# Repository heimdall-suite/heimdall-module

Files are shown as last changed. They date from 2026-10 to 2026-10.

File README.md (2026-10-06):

# heimdall-module

ESP32-C3 based module for the transmitter's JR module bay, part of the Heimdall Suite.

## Status

Hardware rev 2 (KiCad 10, `hardware/kicad/`): schematic reviewed and corrected,
board re-placed and re-routed from the first EasyEDA layout. Not built or tested
yet. The EasyEDA originals are kept in `hardware/easyeda-archive/`. No firmware yet.

KiCad 3D renders of rev 2:

| Top, angled | Bottom, angled |
|---|---|
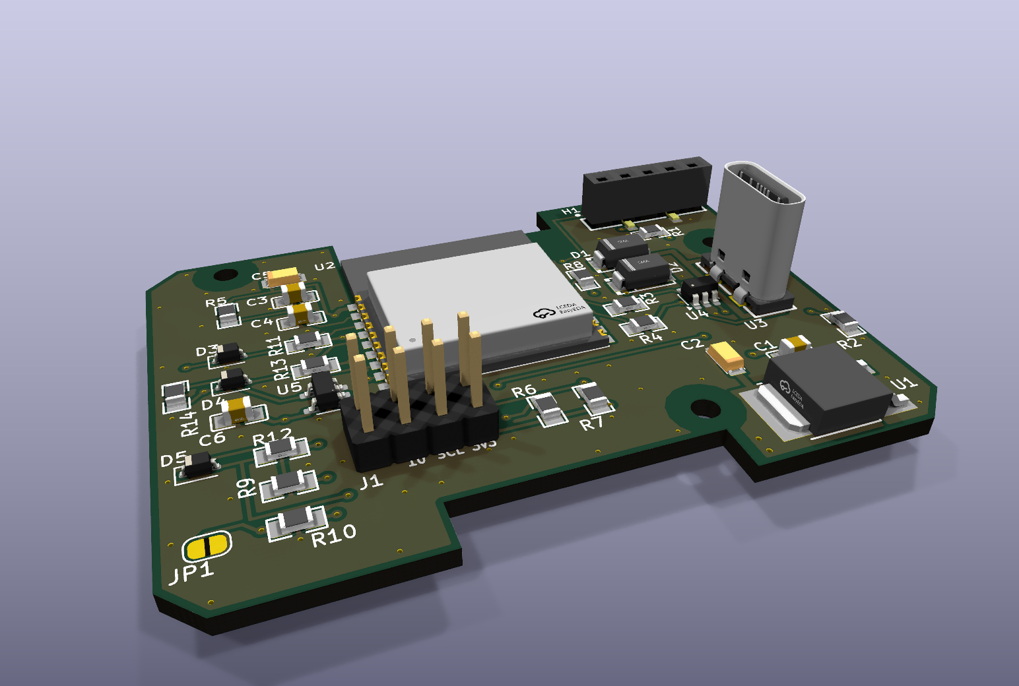
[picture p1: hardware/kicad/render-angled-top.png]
Board, 3D top, angled
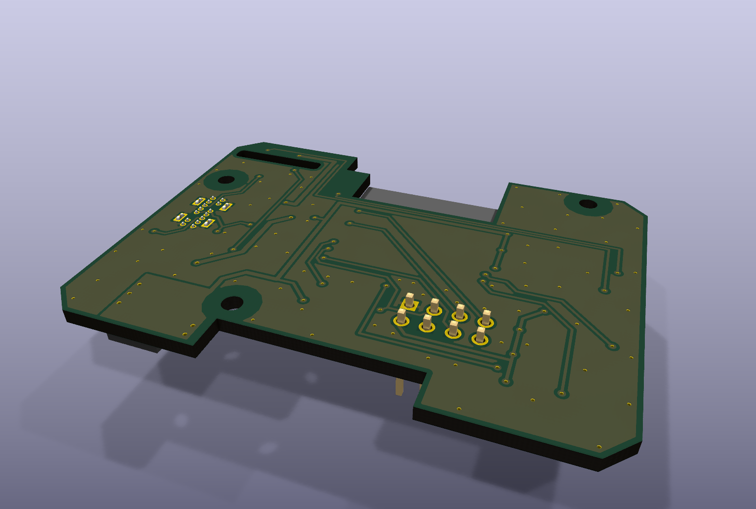
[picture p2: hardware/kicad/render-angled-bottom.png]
Board, 3D bottom, angled
|  |  |

| Top | Bottom (mirrored, as seen from below) |
|---|---|
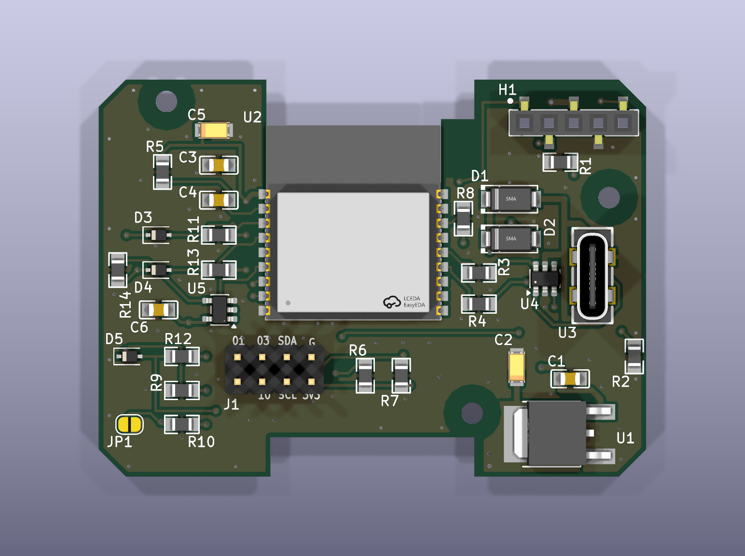
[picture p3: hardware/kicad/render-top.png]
Board, 3D top
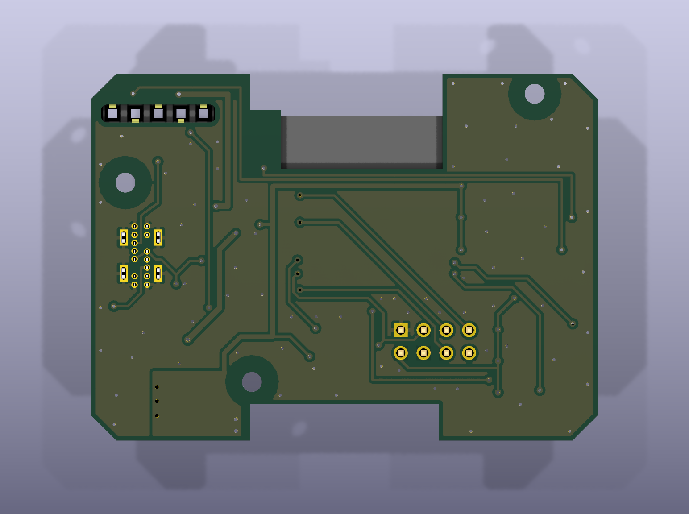
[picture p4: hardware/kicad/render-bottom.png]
Board, 3D bottom
|  |  |

## Case

The board is shaped for the 3D-printed case `MULTI-Module_Bangood_4-in-1_Case.stl`
(the STL is not in this repo). The figures below were measured from that STL:

- The outline is the case cavity (57 x 41.5 mm) minus 0.3 mm all round. It has
  notches for the two latch housings, which reach 4 mm in from the long walls.
  The top notch merges with the cut-out under the ESP32 module's antenna.
- The four corners are chamfered 45° (2.8 mm legs). The lid screw holes
  (1.7 mm) sit in 3.5 mm bosses in the cavity corners, from about 11 mm above
  the floor upwards. The board has to pass them on the way down to the
  standoffs, and the chamfers leave about 0.47 mm to each boss.
- MH1-MH3 are 2.2 mm holes for 2 mm self-tapping screws into the case's three
  standoffs (4.5 mm, 1.8 mm pilot holes, tops 5 mm above the floor).
  The lid uses the same screws. The copper keeps 3 mm clear of each hole.
- The bay pins come up through the floor opening and the H1 slot into the
  female header on top.
- **H1 position:** taken from three existing JR-bay designs. All three put the
  bay pins about 1.25 mm closer to the end wall than the centre of the case's
  floor opening:
  - DIY Multiprotocol STM32 v1.0t (Eagle)
  - Multiprotocol V2 (Gerbers)
  - ExpressLRS TX_SX1280 (Gerbers)

  This is not yet checked against a real radio.
- The case still needs an opening for the USB-C connector.

`case_place.py` moved the rev 2 parts into the case outline. `spread_place.py`
then spread them for hand soldering: at least 1 mm between courtyards left of the
module, and U1 moved down to the bottom edge. A few pairs on the USB side are
still closer. `route_pcb.py prep` draws the hand routes; Freerouting and the
later `route_pcb.py` steps do the rest.

## Pin assignment (rev 2)

| Function | ESP32-C3 GPIO | Via |
|---|---|---|
| Bay SIGNAL / PPM (H1 pin 1), input | IO4 | D3, R11 4.7k pull-up |
| Bay DATA / S.Port (H1 pin 5), receive | IO5 | D4, R13 4.7k pull-up |
| Bay DATA / S.Port (H1 pin 5), transmit | IO7 | U5 74LVC1G34 + R14 1k |
| Bay HB (H1 pin 2), output | IO8 | D5 (pull low only), R9 doubles as its pull-up |
| I2C SDA / SCL (J1, 10k pull-ups) | GPIO20 / GPIO21 (U0RXD / U0TXD) | |
| Breakout (J1) | IO1, IO3, IO10 | |
| USB D- / D+ | IO18 / IO19 | R4 / R3 33R |
| Strapping | IO2, IO8 (HB), IO9 pulled up 10k; JP1 BOOT bridges IO9 to GND | |

IO0 and IO6 are unused. UART0's pins carry I2C, so the console has to run over
USB-Serial/JTAG.

## Bay interface

The bay lines never connect straight to the ESP32.

- SIGNAL (PPM in) and DATA receive go through a BAT54WS Schottky with its
  cathode at the bay, the same scheme as the DIY Multiprotocol module (STM32
  board v1.0t, BAT48 diodes). The radio can only pull the line low; the high
  level comes from our 3V3 pull-ups (R11, R13), so a radio that drives 5 V
  never reaches the ESP32.
- HB (out) goes through a Schottky with its anode at the bay: the ESP32 can
  only pull it low, R12 (4.7k) pulls it high on the bay side.
- DATA transmit goes through U5, a 74LVC1G34 buffer (5.5 V tolerant, always on),
  and R14 (1k). The UART's idle level holds the line, so the same hardware
  works for CRSF (idle high) and inverted S.Port (idle low); which one is a
  firmware setting. When the radio transmits it overrides the 1k (about
  3.3 mA). Against a 10k pull-up on the radio side, an S.Port idle low sits at
  about 0.3 V (calculated, not measured).

DATA is half duplex on one wire, with separate receive and transmit pins
(IO5/IO7). The receive pin also sees the module's own transmitted bytes, so
firmware has to discard that echo. Inversion is done in the ESP32-C3's UART.
Use IO8 (HB) as an output only after boot: it is a strapping pin, which is
safe here because download mode needs USB, and USB and the bay can't be
connected at the same time.

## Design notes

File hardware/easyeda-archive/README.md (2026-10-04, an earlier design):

# EasyEDA Pro archive

The original heimdall-module design was drawn in EasyEDA Pro 3.2 (project
"Atmosphere module") before the move to KiCad. These files are kept
unmodified as a reference:

- `Schematic1.epro`, `PCB1.epro` — per-document exports from EasyEDA Pro
  (2026-10-04). The full project's native `.epro2` format can't be read by
  the KiCad 10 importer, these older-format exports can.
- `merge_epro.py` — joins the two exports into one linked project,
  `heimdall-module.epro`, for KiCad's File → Import → Non-KiCad Project.

Once imported, `hardware/kicad/` is the source of truth; nothing here is
edited further.

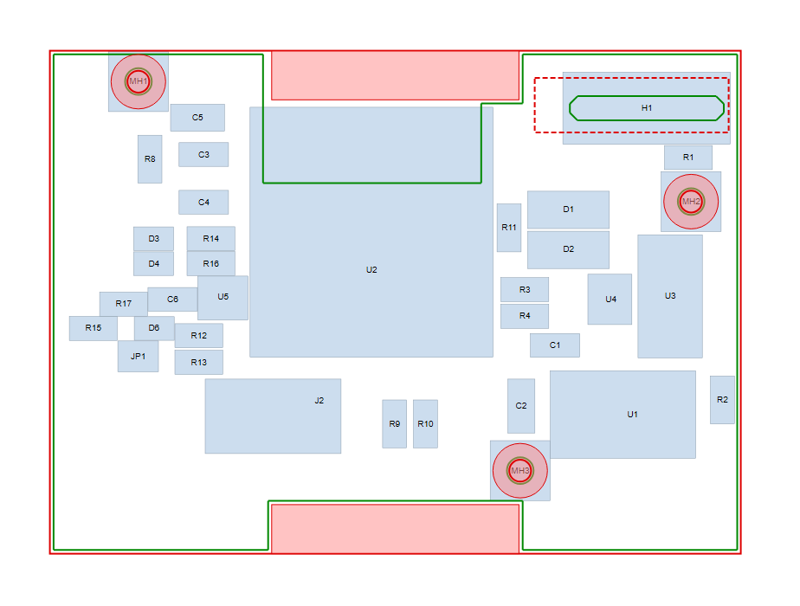
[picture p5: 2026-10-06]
hardware/kicad/placement-overlay.png

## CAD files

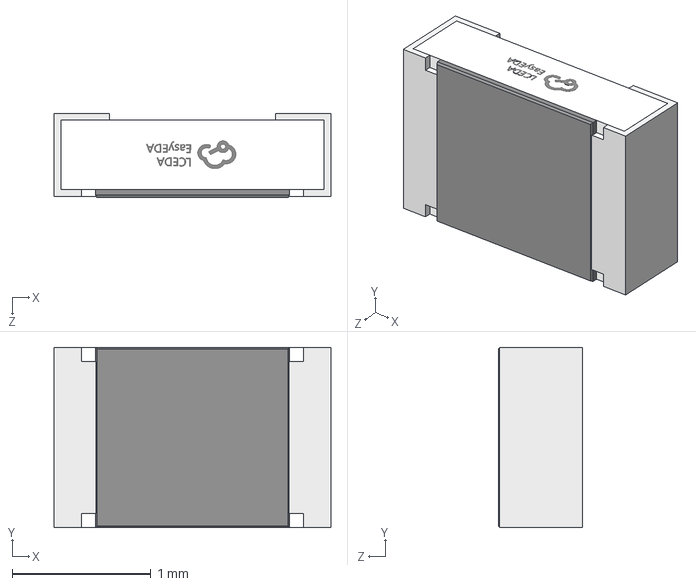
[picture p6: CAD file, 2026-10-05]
hardware/kicad/EASYEDA_MODELS/R0805_L2.0-W1.3-H0.6.step
2.00 x 1.30 x 0.61 mm

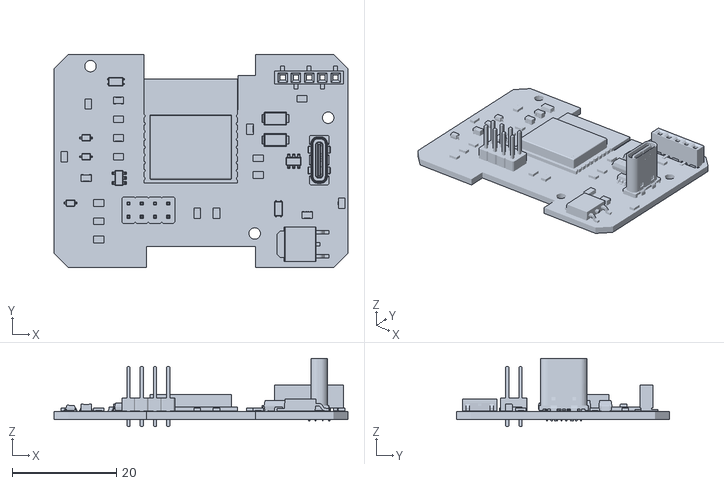
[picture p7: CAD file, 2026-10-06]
hardware/kicad/pcb.stl
56.4 x 40.9 x 13.1

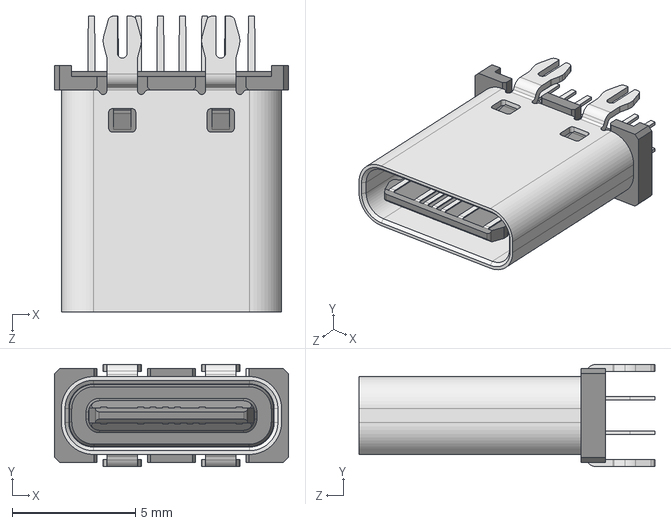
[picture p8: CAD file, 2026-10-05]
hardware/kicad/EASYEDA_MODELS/USB-TYPE-C-TH_TYPEC-214-ARP14H105.step
9.50 x 4.16 x 12.0 mm

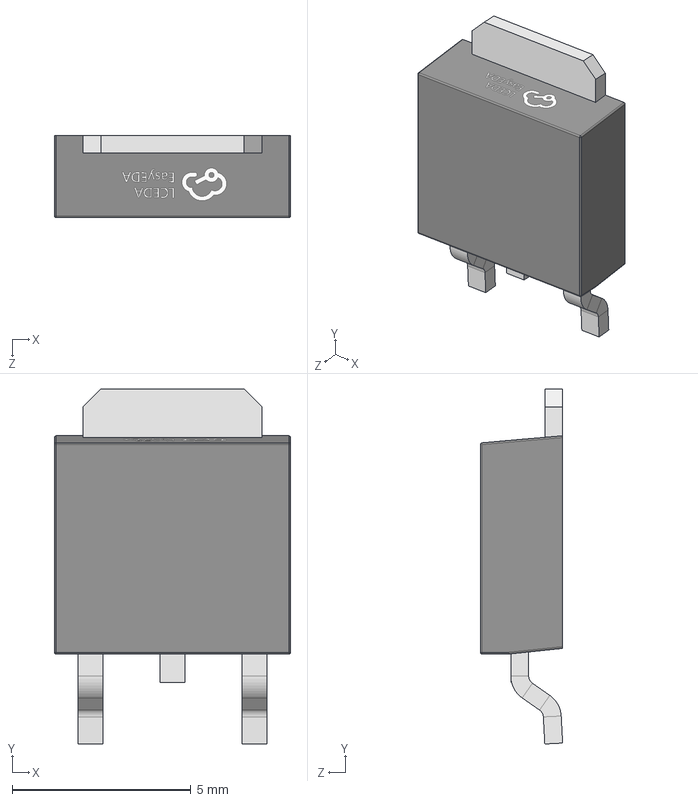
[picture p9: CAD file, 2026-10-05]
hardware/kicad/EASYEDA_MODELS/TO-252-2L-3P_L6.6-W6.1-H2.3-LS10.1-P4.6.step
6.60 x 9.92 x 2.30 mm

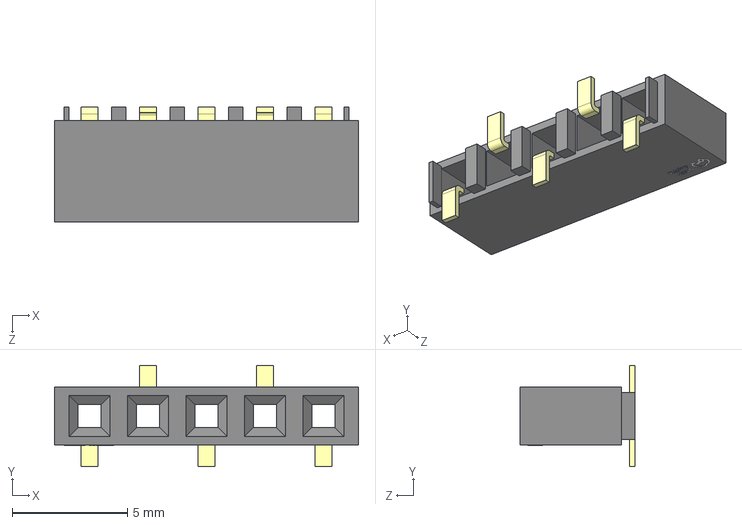
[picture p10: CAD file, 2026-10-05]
hardware/kicad/EASYEDA_MODELS/HDR-SMD_5P-P2.54-V-F-LS4.4.step
13.2 x 4.40 x 5.00 mm

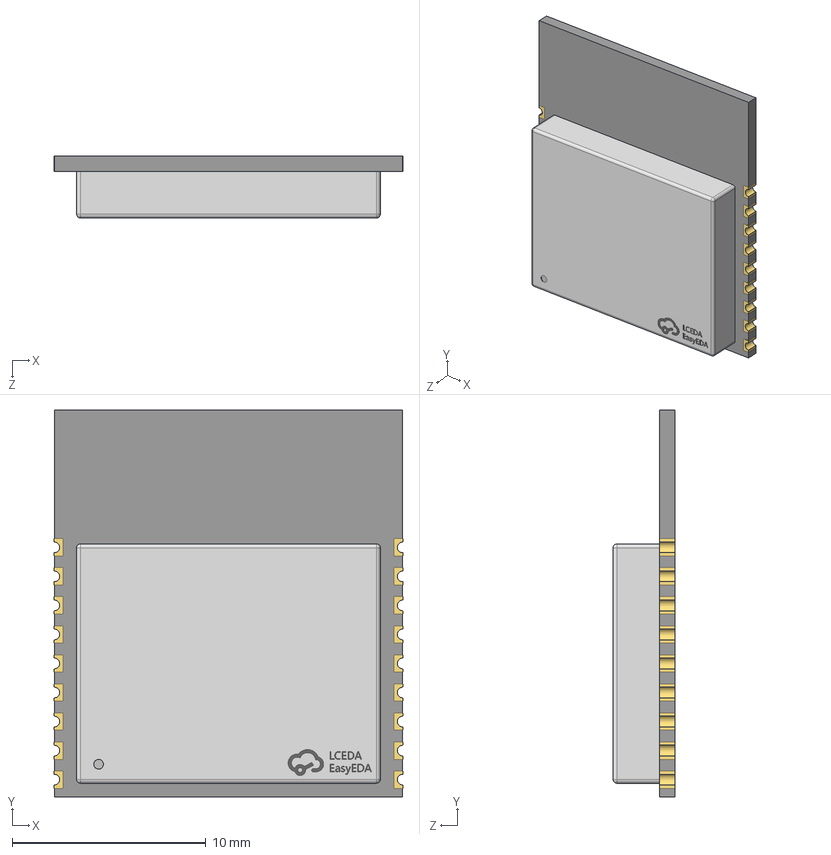
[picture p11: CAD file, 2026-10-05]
hardware/kicad/EASYEDA_MODELS/BULETM-SMD_ESPRESSIF_ESP32-C3-WROOM-02-N4-4MB.step
18.0 x 20.0 x 3.22 mm

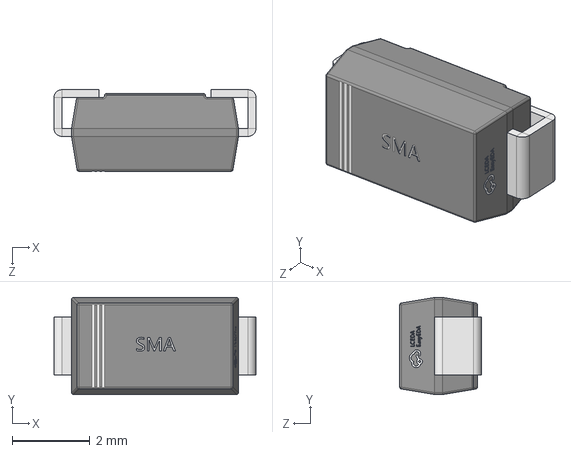
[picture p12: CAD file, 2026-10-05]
hardware/kicad/EASYEDA_MODELS/SMA_L4.4-W2.6-LS5.0-RD.step
5.20 x 2.50 x 2.10 mm

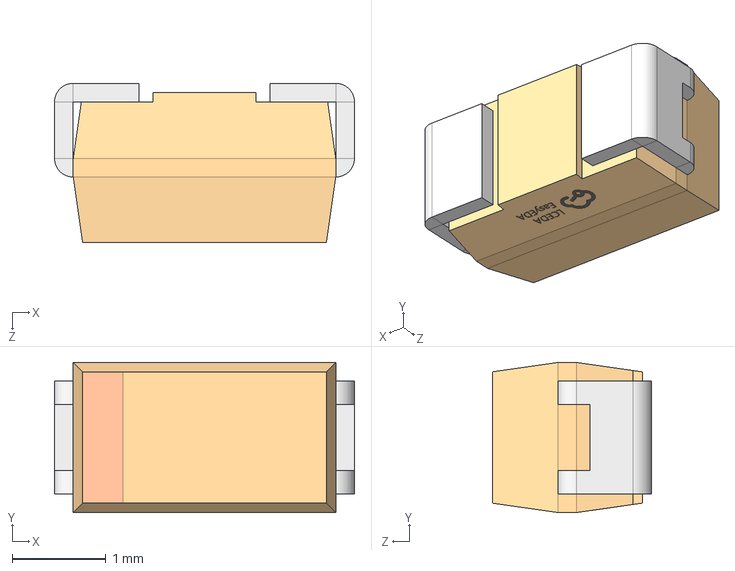
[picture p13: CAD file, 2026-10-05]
hardware/kicad/EASYEDA_MODELS/CASE-A_3216.step
3.20 x 1.60 x 1.70 mm

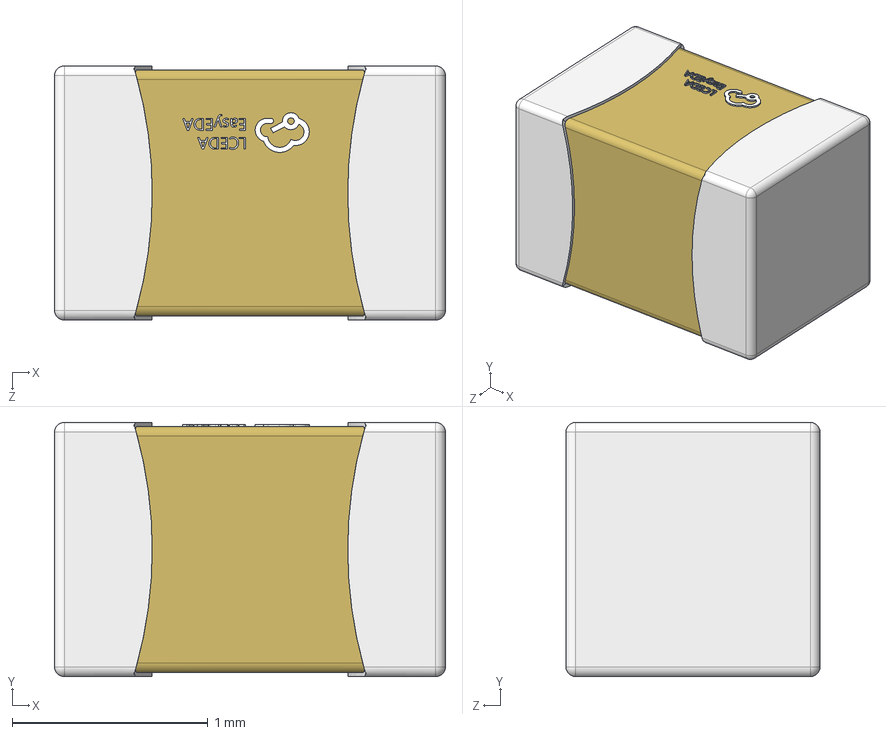
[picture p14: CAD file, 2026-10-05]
hardware/kicad/EASYEDA_MODELS/C0805_L2.0-W1.3-H1.3.step
2.00 x 1.30 x 1.30 mm

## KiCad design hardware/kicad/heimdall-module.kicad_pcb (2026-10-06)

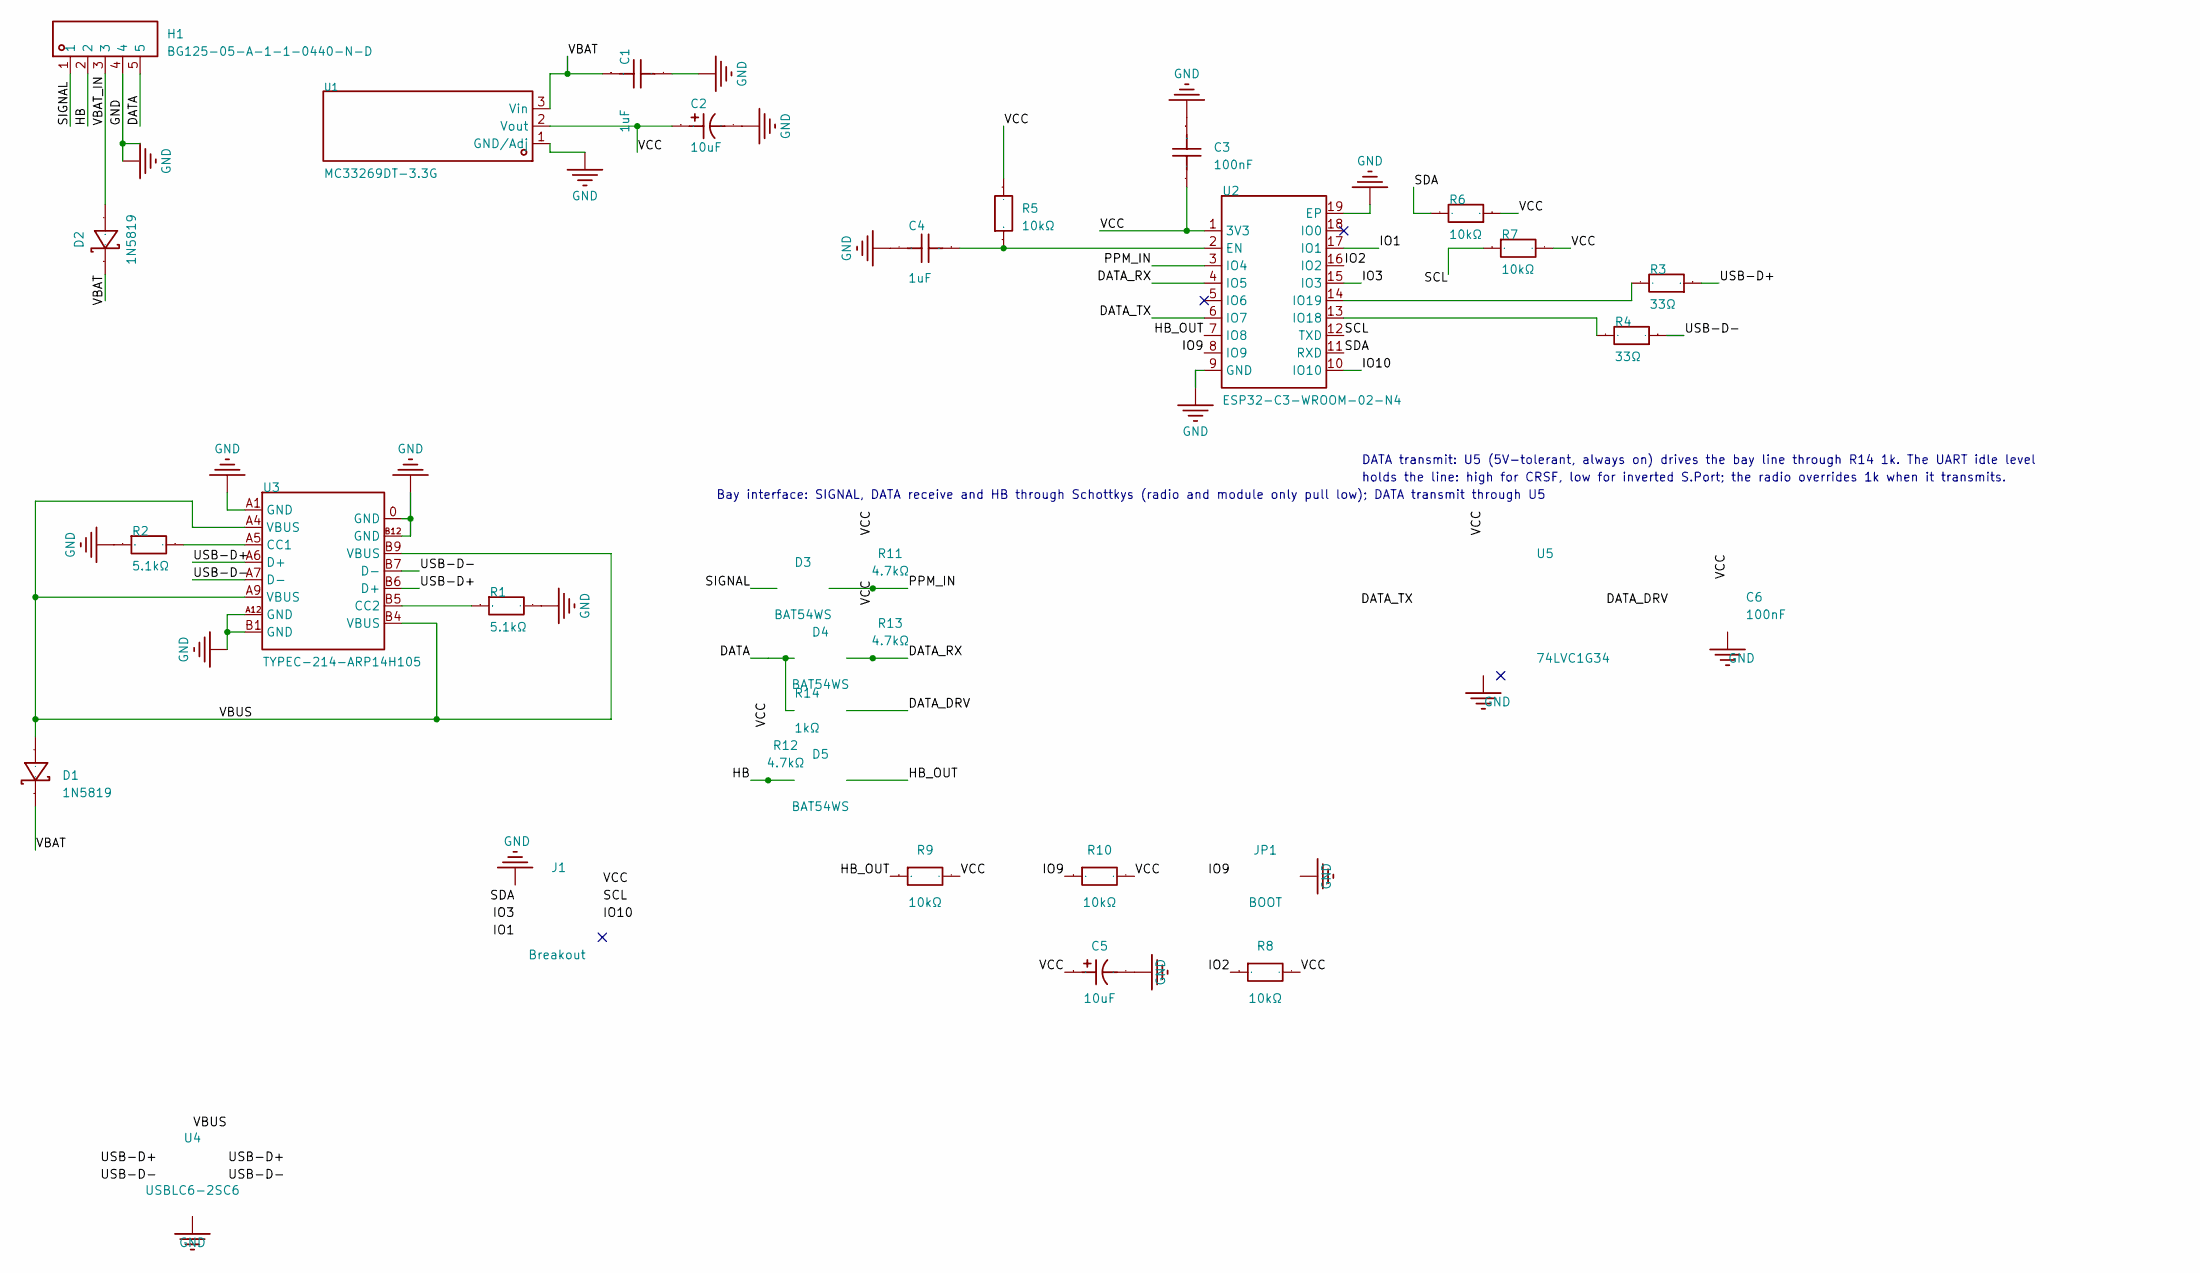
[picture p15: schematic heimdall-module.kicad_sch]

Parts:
C1, C4: 1uF; C0805; Manufacturer Part GCM21BR71H105KA03L
C2: 10uF; CASE-A_3216; Manufacturer Part T491A106K010AT; LCSC Part Name 10uF ±10% 10V
C3: 100nF; C0805; Manufacturer Part GRM21B7U1A104JA01L; LCSC Part Name 100nF ±5% 10V
C5: 10uF; CASE-A_3216; Manufacturer Part T491A106K010AT
C6: 100nF; C0805; Manufacturer Part GRM21B7U1A104JA01L
D1: 1N5819; SMA_L4.4-W2.6-LS5.0-RD; Manufacturer Part 1N5819; LCSC Part Name KEXIN(科信)原型号 SS14,后续变更为 1N5819，丝印不变。 电压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
D2: 1N5819; SMA_L4.4-W2.6-LS5.0-RD; Manufacturer Part 1N5819
D3, D4, D5: BAT54WS; D_SOD-323; Manufacturer Part BAT54WS-7-F
H1: BG125-05-A-1-1-0440-N-D; HDR-SMD_5P-P2.54-V-F-LS4.4; Manufacturer Part BG125-05-A-1-1-0440-N-D; LCSC Part Name 1x5P 间距:2.54mm 立贴
J1: Breakout; PinHeader_2x04_P2.54mm_Vertical
JP1: BOOT; SolderJumper-2_P1.3mm_Open_RoundedPad1.0x1.5mm
R1, R2: 5.1kΩ; R0805; Manufacturer Part ERA6AEB512V; LCSC Part Name 薄膜电阻 5.1kΩ ±0.1% 125mW
R3, R4: 33Ω; R0805; Manufacturer Part ERJ6ENF33R0V; LCSC Part Name 33Ω ±1% 125mW 厚膜电阻
R5, R6, R7: 10kΩ; R0805; Manufacturer Part ERJP06F1002V; LCSC Part Name 10kΩ ±1% 500mW 厚膜电阻
R8, R9, R10: 10kΩ; R0805; Manufacturer Part ERJP06F1002V
R11, R12, R13: 4.7kΩ; R0805; Manufacturer Part ERJ-6ENF4701V
R14: 1kΩ; R0805; Manufacturer Part ERJ-6ENF1001V
U1: MC33269DT-3.3G; TO-252-2_L6.6-W6.1-P4.57-LS9.9-BR-CW; Manufacturer Part MC33269DT-3.3G; LCSC Part Name 3.3V 800mA 20V
U2: ESP32-C3-WROOM-02-N4; BULETM-SMD_ESPRESSIF_ESP32-C3-WROOM-02-N4-4MB; Manufacturer Part ESP32-C3-WROOM-02-N4; LCSC Part Name 不带固件 2.4GHz Wi-Fi（802.11b/g/n）+ 蓝牙5模组
U3: TYPEC-214-ARP14H105; USB-TYPE-C-TH_TYPEC-214-ARP14H105; Manufacturer Part TYPEC-214-ARP14H105; LCSC Part Name Type-C 母 直插
U4: USBLC6-2SC6; SOT-23-6; Manufacturer Part USBLC6-2SC6
U5: 74LVC1G34; SOT-23-5; Manufacturer Part SN74LVC1G34DBVR

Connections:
/DATA: D4.1 (K), H1.5, R14.1
/DATA_DRV: R14.2, U5.4
/DATA_RX: D4.2 (A), R13.2, U2.4 (IO5)
/DATA_TX: U2.6 (IO7), U5.2
/HB: D5.2 (A), H1.2, R12.2
/HB_OUT: D5.1 (K), R9.1, U2.7 (IO8)
/IO1: J1.7, U2.17 (IO1)
/IO2: R8.1, U2.16 (IO2)
/IO3: J1.5, U2.15 (IO3)
/IO9: JP1.1 (A), R10.1, U2.8 (IO9)
/IO10: J1.6, U2.10 (IO10)
/PPM_IN: D3.2 (A), R11.2, U2.3 (IO4)
/SCL: J1.4, R7.1, U2.12 (TXD)
/SDA: J1.3, R6.2, U2.11 (RXD)
/SIGNAL: D3.1 (K), H1.1
/USB-D+: R3.1, U3.A6 (D+), U3.B6 (D+), U4.1 (I/O1), U4.6 (I/O1)
/USB-D-: R4.1, U3.A7 (D-), U3.B7 (D-), U4.3 (I/O2), U4.4 (I/O2)
/VBAT: C1.1, D1.1 (C), D2.1 (C), U1.3 (Vin)
/VBAT_IN: D2.2 (A), H1.3
/VBUS: D1.2 (A), U3.A4 (VBUS), U3.A9 (VBUS), U3.B4 (VBUS), U3.B9 (VBUS), U4.5 (VBUS)
/VCC: C2.1, C3.2, C5.1, C6.1, J1.2, R5.2, R6.1, R7.2, R8.2, R9.2, R10.2, R11.1, R12.1, R13.1, U1.2 (Vout), U2.1 (3V3), U5.5 (VCC)
GND: C1.2, C2.2, C3.1, C4.2, C5.2, C6.2, H1.4, J1.1, JP1.2 (B), R1.2, R2.1, U1.1 (GND/Adj), U2.9 (GND), U2.19 (EP), U3.0 (GND), U3.A1 (GND), U3.A12 (GND), U3.B1 (GND), U3.B12 (GND), U4.2 (GND), U5.3 (GND)
unnamed: C4.1, R5.1, U2.2 (EN)
unnamed: R4.2, U2.13 (IO18)
unnamed: R3.2, U2.14 (IO19)
unnamed: R2.2, U3.A5 (CC1)
unnamed: R1.1, U3.B5 (CC2)

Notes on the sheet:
Bay interface: SIGNAL, DATA receive and HB through Schottkys (radio and module only pull low); DATA transmit through U5
DATA transmit: U5 (5V-tolerant, always on) drives the bay line through R14 1k. The UART idle level
holds the line: high for CRSF, low for inverted S.Port; the radio overrides 1k when it transmits.

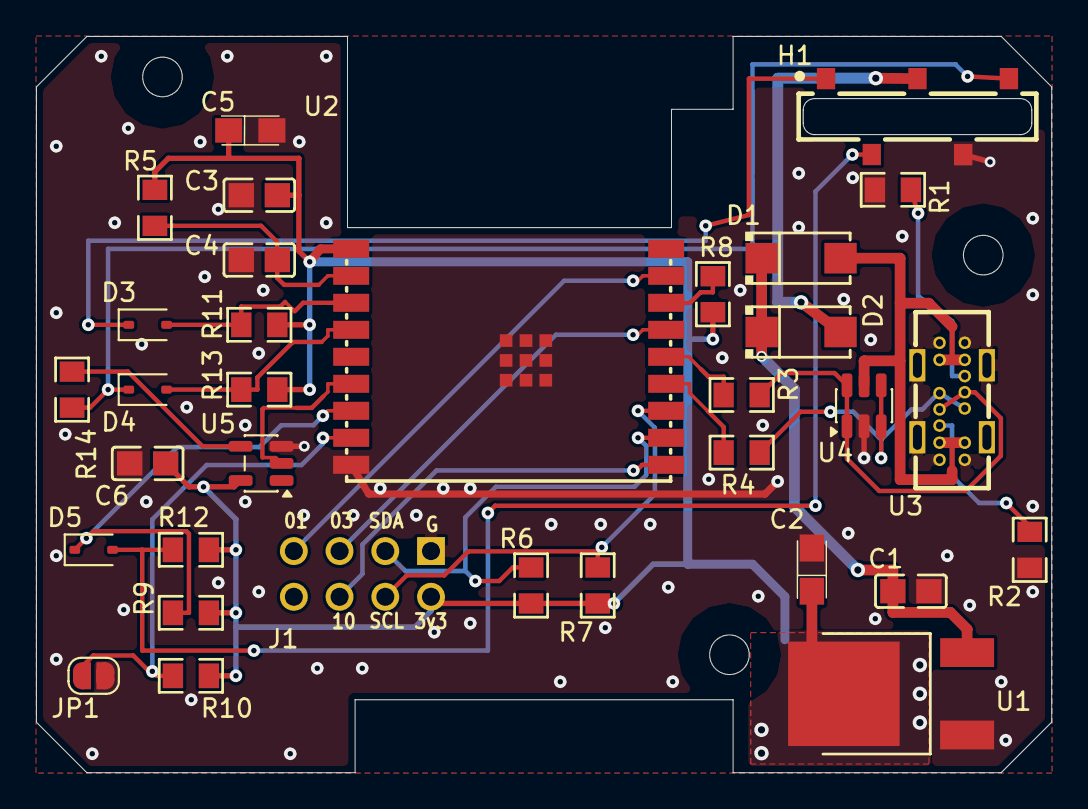
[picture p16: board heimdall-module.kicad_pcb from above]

Board: 2 copper layers, 56.4 x 40.9 mm, 36 parts (0 on the bottom side), 27 nets.

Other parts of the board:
MH1, MH2, MH3: M2; MountingHole_2.2mm_M2_ISO14580

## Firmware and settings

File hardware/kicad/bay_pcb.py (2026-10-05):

"""Bay interface on the PCB: sync to the netlist (D5 out; U5/C6 in, R17 moved), place, strip copper.
Run with KiCad's python from hardware/kicad:  python bay_pcb.py NETLIST.xml"""
import sys, pcbnew, xml.etree.ElementTree as ET

B = 'heimdall-module.kicad_pcb'
STD = r'C:/Users/svefre/AppData/Local/Programs/KiCad/10.0/share/kicad/footprints'
PRJLIB = 'heimdall-m-easyedapro'
IO = pcbnew.PCB_IO_KICAD_SEXPR()
MM = pcbnew.FromMM
V = lambda x, y: pcbnew.VECTOR2I(MM(x), MM(y))

b = pcbnew.LoadBoard(B)
net = ET.parse(sys.argv[1]).getroot()
comps = {c.get('ref'): c for c in net.iter('comp')}
pinnet = {(n2.get('ref'), n2.get('pin')): n.get('name') for n in net.iter('net') for n2 in n.iter('node')}

def load(fpid):
    nick, name = fpid.split(':')
    f = IO.FootprintLoad(PRJLIB + '.pretty' if nick == PRJLIB else '%s/%s.pretty' % (STD, nick), name)
    f.SetFPID(pcbnew.LIB_ID(nick, name))
    return f

# rows follow module pins 3..6 (IO4 PPM_IN, IO5 DATA_RX, IO6 DATA_TX, IO7 HB_OUT)
RA, RB, RC, RD = 101.9, 103.95, 106.0, 108.05
XD, XB, XM = 127.7, 123.1, 132.4
PLACE = {
    'D3': (XD, RA, 0), 'D4': (XD, RB, 0),            # K at the bay (left)
    'R14': (XM, RA, 180), 'R16': (XM, RB, 180),      # MCU-side pull-ups, VCC pad right
    # DATA transmit in the band below row B: U5 beside module pads 6/7, C6 next to it, R17 by the DATA via
    'U5': (133.4, 106.7, 180), 'C6': (129.25, 106.9, 180), 'R17': (125.2, 107.3, 0),
    # HB a step lower to make room: D6 (A at the bay, left) and its pull-up R15
    'D6': (XD, 109.3, 180), 'R15': (122.7, 109.3, 0),
    'R12': (131.4, 109.9, 0), 'R13': (131.4, 112.1, 0),   # 0.3 lower, so HB_OUT and U5's VCC via fit above
}

dead = list(b.GetTracks()) + list(b.Zones())
for f in b.GetFootprints():
    ref = f.GetReference()
    if ref and ref not in comps and not f.IsBoardOnly():
        dead.append(f); print('remove', ref)

for ref, c in comps.items():
    f = b.FindFootprintByReference(ref)
    if not f:
        f = load(c.findtext('footprint')); f.SetReference(ref); b.Add(f)
        f.SetPath(pcbnew.KIID_PATH('/' + c.find('tstamps').text))
        f.SetSheetname('/'); f.SetSheetfile('heimdall-module.kicad_sch')
        print('add', ref)
    if ref in PLACE:      # new or changed parts: value and fields from the schematic
        f.SetValue(c.findtext('value'))
        for fld in c.iter('field'):
            if fld.get('name') not in ('Footprint', 'Datasheet', 'Description'):
                f.SetField(fld.get('name'), fld.text or '')
                f.GetField(fld.get('name')).SetVisible(False)
    if ref in PLACE:
        x, y, r = PLACE[ref]
        f.SetPosition(V(x, y)); f.SetOrientationDegrees(r)
        f.Reference().SetLayer(pcbnew.F_Fab)   # too dense for silk refs
    for p in f.Pads():
        name = pinnet.get((ref, p.GetNumber()))
        if name is None:
            p.SetNetCode(0); continue
        ni = b.FindNet(name)
        if ni is None:
            ni = pcbnew.NETINFO_ITEM(b, name); b.Add(ni)
        p.SetNet(ni)

# JP1's reference would sit on D6 (one row lower now): left of the jumper instead
b.FindFootprintByReference('JP1').Reference().SetPosition(V(122.8, 112.0))

for it in dead:
    b.Remove(it)
pcbnew.SaveBoard(B, b)
for r in sorted(PLACE):
    f = b.FindFootprintByReference(r)
    print(r, [(p.GetNumber(), p.GetNetname(), round(pcbnew.ToMM(p.GetPosition().x), 2), round(pcbnew.ToMM(p.GetPosition().y), 2)) for p in f.Pads()])

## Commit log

2026-10-04 Archive the EasyEDA Pro design before moving to KiCad
    The first heimdall-module schematic and PCB were drawn in EasyEDA Pro
    3.2. KiCad 10 can't import the native .epro2 project, so the schematic
    and PCB were exported separately in the older .epro format. merge_epro.py
    joins them into one linked project for KiCad's Non-KiCad Project import.
2026-10-04 Import the EasyEDA design into KiCad 10
    The schematic came from KiCad's Non-KiCad Project import, which skipped the
    PCB. The board was imported with kicad-cli instead. Its footprints were
    saved into heimdall-m-easyedapro.pretty and linked to the schematic
    symbols by reference. Not yet synced with Update PCB from Schematic, so
    net names and fields still differ (DRC parity).
    [heimdall-module.kicad_pcb, heimdall-module.kicad_sch]
2026-10-04 Sync the imported PCB with the schematic and clean up ERC
    After Update PCB from Schematic, the pads were on the new hierarchical
    nets (/VCC, /SDA, ...) but tracks, vias and zones kept the old names;
    moved them over. Removed EasyEDA's A4 frame symbol and empty Field42
    properties. Gave pins real types: passives, connectors and diode are
    passive, MC33269 Vin/Vout are power in/out, ESP32 IOs bidirectional.
    GND is now a KiCad power symbol. ERC is down from 100 to 19 and DRC from
    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
    [heimdall-module.kicad_pcb, heimdall-module.kicad_sch]
2026-10-04 Schematic revision: strapping, decoupling, ESD, reverse feed, breakout
    - IO2 and IO8 had no pull-ups. Espressif's checklist needs IO2 high for
    every boot mode and IO8 high for download boot. Added 10k pull-ups
    (R11, R12), plus a 10k pull-up on IO9 (R13, recommended) and a solder
    jumper to GND (JP1 BOOT) for forcing download mode.
    - EN delay cap C4: 100nF -> 1uF (Espressif: 10k + 1uF).
    - C5 10uF tantalum at the module's 3V3 pin. The regulator's 10uF (C2) is
    ~25mm of trace away, and the MC33269 datasheet warns against low-ESR
    ceramics close to its output, hence tantalum.
    - C1 (LDO input) tantalum -> 1uF 50V X7R ceramic: no ESR need on the
    input, and no tantalum surge failure on hot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
    [heimdall-module.kicad_sch]
2026-10-04 Rev 2: corrected schematic, re-placed and re-routed board
    Schematic (on top of the previous commit):
    - I2C moved from IO0/IO1 to GPIO20/21 and bay SIGNAL/DATA swapped onto
    IO4/IO5, so the right-hand pins can reach J2 without crossing the 3V3
    trunk. No firmware exists yet. SCL sits on U0TXD (boot log); SDA stays a
    pulled-up input, so no I2C start condition happens at boot. The console
    has to use USB-Serial/JTAG.
    - JP1 kept out of BOM/position files; U2 value -> part name.
    PCB:
    - H1 slot restored: EasyEDA had it as a multi-layer fill (became copper
    in the import). Now a 12.7 x 2.03mm cut-out, H1's pads trimmed to end
    0.5mm before it.
    - All copper rebuilt: power class 0.6mm (VBUS,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
    [heimdall-module.kicad_pcb, heimdall-module.kicad_sch]
2026-10-05 Schematic tidy-up, PWR_FLAGs at the supply entries, 3D models
    - Schematic rearranged in the GUI (connectivity unchanged, checked
    against the previous netlist). PWR_FLAGs moved from the loose corner of
    the sheet to where the supplies enter: VBAT on D2's output, GND on H1
    pin 4. ERC 0.
    - 3D models: the import pointed the footprints at
    ${KIPRJMOD}/EASYEDA_MODELS/*.step but the .epro exports don't carry the
    files. Downloaded EasyEDA's STEP model for each part (looked up by the
    LCSC number) into EASYEDA_MODELS/. The import got two placements wrong
    (model origin at one end, not the centre): H1 offset -6.6/-0.9mm, U1
    (DPAK) 4.45/-2.2mm at -90 deg, set on the board and in the library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
    [BULETM-SMD_ESPRESSIF_ESP32-C3-WROOM-02-N4-4MB.step, C0805_L2.0-W1.3-H1.3.step, CASE-A_3216.step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]
2026-10-05 H1 slot 2.03 -> 2.00mm wide (same centre line and length)
    [heimdall-module.kicad_pcb]
2026-10-05 Bay interface: Schottky isolation on all bay signal lines
    The bay lines no longer connect straight to the ESP32 through 220R
    (R5-R7 removed). Each line goes through a BAT54WS (D3-D6), the same
    scheme as the DIY Multiprotocol module: the radio can only pull a line
    low, and every high level comes from 3V3 pull-ups. A radio driving 5V
    can't reach the ESP32.
    - PPM in: D3 + R14 4.7k -> IO4
    - DATA (CRSF, half duplex): RX D4 + R16 4.7k -> IO5, TX D5 <- IO6,
    R17 1.5k bay-side pull-up for fast rising edges
    - HB out: D6 <- IO7, R15 4.7k bay-side pull-up
    - Breakout J2 pin 7: IO7 -> IO1 (silk relabelled)
    Board re-routed (prep -> Freerouting -> finish pipeline). DRC: 0 errors,
    0 unconnected, 0 parity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
    [heimdall-module.kicad_pcb, heimdall-module.kicad_sch]
2026-10-05 Bay DATA transmit through a 5V-tolerant buffer: S.Port and CRSF
    The module has to talk S.Port (idle low, inverted) or CRSF (idle high)
    on the DATA pin depending on what the internal module uses. The
    pull-low-only diode and the 1.5k pull-up only worked for CRSF.
    - D5 and the 1.5k pull-up out; U5 74LVC1G34 (always on) + R17 1k in.
    The UART idle level holds the line in either mode; the radio
    overrides 1k when it transmits.
    - DATA_TX on IO7, HB_OUT on IO8 (R12 doubles as its pull-up), IO6 free.
    - D6/R15 one step lower, R12/R13 0.3mm lower; DATA, HB, HB_OUT, D+/D-
    and the U5 supply hand-routed in route_pcb.py prep.
    DRC: 0 unconnected, 0 parity. Two starved-thermal warnings: U3 A1 (as
    befo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
    [heimdall-module.kicad_pcb, heimdall-module.kicad_sch]
2026-10-05 Fit the board to the Banggood 4-in-1 Multi case
    Board outline = case cavity (57 x 41.5mm) - 0.3mm, notches for the latch
    housings, M2 holes on the case's three standoffs (copper kept 2mm clear),
    measured from MULTI-Module_Bangood_4-in-1_Case.stl.
    - H1 + slot moved 1.25mm towards the end wall and 0.25mm towards the case
    centre: the bay pin position three JR-bay designs agree on (Multi
    STM32 v1.0t Eagle, Multipro V2 Gerbers, ELRS TX_SX1280 Gerbers)
    - module and left side 2.8mm down (antenna end clears the latch housing),
    USB/ESD/diodes 3.7mm down, U1 also 4.1mm right, C2 beside U1's tab,
    R1/R2 moved; MH1/MH2 replaced by MH1-MH3 on the standoffs
    - route_pcb.py prep draws hand routes pe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
    [heimdall-module.kicad_pcb]
2026-10-05 Mounting holes for M3 instead of M2
    MH1-MH3: MountingHole_3.2mm_M3_ISO14580 (5.5mm head), copper kept 3mm
    clear. To make room at MH2/MH3: R1 moved left of H1's pin 4, CC2 and the
    VBUS exit rerouted round the hole, USB group 0.3mm lower (GND spine and HB
    follow), U1 0.5mm further right with the heatsink copper widened, R9/R10
    VCC hand-routed into the bottom heatsink copper.
    DRC: 0 unconnected, 0 parity; starved-thermal warnings on U3 A1 and J2
    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
    [heimdall-module.kicad_pcb]
2026-10-05 3D models: USB-C and 0805 capacitors sit on the board
    The EasyEDA STEP for the 0805 capacitors is centred on its own origin
    (z -0.65..+0.65): offset +0.65. The vertical USB-C model's body ends at
    z -2.6 with only the pins below; its imported offset was -2.0, which put
    the housing through the board: offset +2.6 (about 10.3mm above the
    board, pins just through a 1.6mm board). Set on the board and in the
    project library footprints.
    [heimdall-module.kicad_pcb]
2026-10-05 3D model: H1 sits on its pads
    The EasyEDA STEP for the SMD female header has its solder feet at
    z -0.44..0 and the body from 0 up: offset +0.44 so the feet rest on the
    board. Set on the board and in the project library footprint.
    [heimdall-module.kicad_pcb]
2026-10-05 README: 3D renders of the rev 2 board, drop the case-floor note
    The "board sits 2 mm above the case floor, cut pins flush" statement
    was not correct.
2026-10-05 Close board outline: fix slot edge endpoints
    The straight sides of the rounded slot overshot the corner arcs by
    0.01 mm at each end, leaving the Edge.Cuts outline open so 3D/STL
    export failed.
    [heimdall-module.kicad_pcb]
2026-10-06 Fit the case's lid bosses, M2 screws, spread parts for hand soldering
    Case fit (measured on the printed case):
    - Board corners chamfered 45 deg (2.8mm legs): the lid screw bosses
    (1.7mm holes, 3.5mm bosses in the cavity corners) stopped the board
    on its way down to the standoffs. ~0.47mm left to each boss.
    - MH1-MH3 3.2mm (M3) -> 2.2mm for 2mm self-tapping screws into the
    standoffs' 1.8mm pilots; the lid uses the same screws. Copper keepout
    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
    [heimdall-module.kicad_pcb, heimdall-module.kicad_sch]
2026-10-06 Board STL for the case fit, placement overlay image
    pcb.stl: kicad-cli STL export of the current board (chamfered corners,
    M2 holes), for test-fitting in the printed case.
    [pcb.stl]
